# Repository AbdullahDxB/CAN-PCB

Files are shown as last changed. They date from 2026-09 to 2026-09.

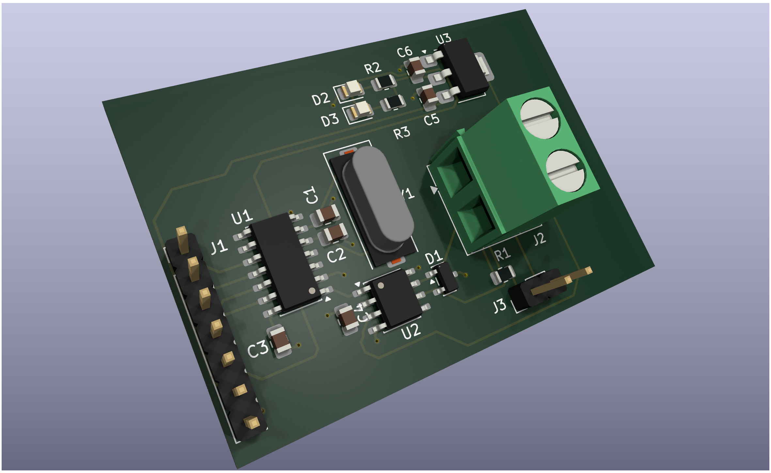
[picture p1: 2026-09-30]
docs/3DVIEW.png

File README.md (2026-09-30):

<h1 align="center">CAN Bus MCP2518 Transceiver Node</h1>

<p align="center">
  <b>High-Integrity Industrial Communication Board</b><br>

</p>

<p align="center">
  
  
  
</p>

<div align="center">
  
  **[View the 3D Board Render](./docs/3DVIEW.png)** &nbsp;&nbsp;•&nbsp;&nbsp; **[View Complete Schematic (PDF)](./docs/Schematic.pdf)**

</div>

---

## 🎯 Project Overview

A robust, two-layer CAN bus transceiver node designed for high-noise industrial environments. Built around the **MCP2518**, this board facilitates reliable, high-speed differential communication. The project demonstrates a strict adherence to layout guidelines, differential pair routing, and rigorous design rule checking (DRC).

## 🛠️ Hardware & Design Stack

* **Transceiver IC:** MCP2518
* **Protocol:** Controller Area Network (CAN)
* **EDA Tool:** KiCAD 9.0 (Schematic Capture, PCB Layout, 3D Rendering)
* **Manufacturing Prep:** Gerber Generation, BOM Management

---

## ⚙️ Design Challenges & Hardware Architecture

1. **Custom Footprint Engineering:** Discovered a critical discrepancy between the default KiCAD footprint library and the manufacturer's datasheet for the transceiver IC. To prevent solder bridging and assembly failure, I manually cross-referenced the physical dimensions and designed a custom footprint from scratch, validating pad spacing against strict DRC parameters.
2. **Differential Pair Routing:** CAN High (CANH) and CAN Low (CANL) traces were strictly routed as differential pairs, ensuring matched impedance and minimizing electromagnetic interference (EMI) in noisy industrial settings.
3. **Design Validation:** Zero errors on both the Electrical Rules Check (ERC) and Design Rules Check (DRC) prior to generating final production files.

---

## 📂 Repository Structure

* **[`hardware/`](./hardware):** Core KiCAD 9.0 project files (`.kicad_sch`, `.kicad_pcb`, `.kicad_pro`).
* **[`docs/`](./docs):** High-resolution schematic PDFs, top/bottom layer copper exports, 3D board renders, and DRC/ERC reports.
* **[`manufacturing/`](./manufacturing):** Generated Bill of Materials (BOM) and production-ready Gerber files.
* **[`datasheets/`](./datasheets):** Component reference documentation.

---
*Created by Abdullah Ajmal - August 2026*

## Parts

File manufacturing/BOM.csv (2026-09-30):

Reference | Qty | Value | DNP | Exclude from BOM | Exclude from Board | Footprint | Datasheet
C1,C2 | 2 | 22pF |  |  |  | Capacitor_SMD:C_0805_2012Metric | ~
C3,C4 | 2 | 100nF |  |  |  | Capacitor_SMD:C_0805_2012Metric | ~
C5,C6 | 2 | 10uF |  |  |  | Capacitor_SMD:C_0805_2012Metric | ~
D1 | 1 | D_TVS_Dual_AAC |  |  |  | Package_TO_SOT_SMD:SOT-23 | ~
D2,D3 | 2 | LED |  |  |  | LED_SMD:LED_0805_2012Metric | ~
J1 | 1 | Conn_01x07 |  |  |  | Connector_PinHeader_2.54mm:PinHeader_1x07_P2.54mm_Vertical | ~
J2 | 1 | Screw_Terminal_01x02 |  |  |  | TerminalBlock_Phoenix:TerminalBlock_Phoenix_MKDS-1,5-2-5.08_1x02_P5.08mm_Horizontal | ~
J3 | 1 | Conn_01x02 |  |  |  | Connector_PinHeader_2.54mm:PinHeader_1x02_P2.54mm_Vertical | ~
R1 | 1 | 120 |  |  |  | Resistor_SMD:R_0805_2012Metric | ~
R2,R3 | 2 | 1k |  |  |  | Resistor_SMD:R_0805_2012Metric | ~
U1 | 1 | MCP2518FD-xQBB |  |  |  | Package_SO:SOIC-14_3.9x8.7mm_P1.27mm | https://ww1.microchip.com/downloads/aemDocuments/documents/OTH/ProductDocuments/DataSheets/External-CAN-FD-Controller-with-SPI-Interface-DS20006027B.pdf
U2 | 1 | MCP2561-E-MF |  |  |  | Package_SO:SOIC-8_3.9x4.9mm_P1.27mm | http://ww1.microchip.com/downloads/en/DeviceDoc/25167A.pdf
U3 | 1 | AMS1117-5.0 |  |  |  | Package_TO_SOT_SMD:SOT-223-3_TabPin2 | http://www.advanced-monolithic.com/pdf/ds1117.pdf
Y1 | 1 | 20MHz |  |  |  | Crystal:Crystal_SMD_HC49-SD | ~

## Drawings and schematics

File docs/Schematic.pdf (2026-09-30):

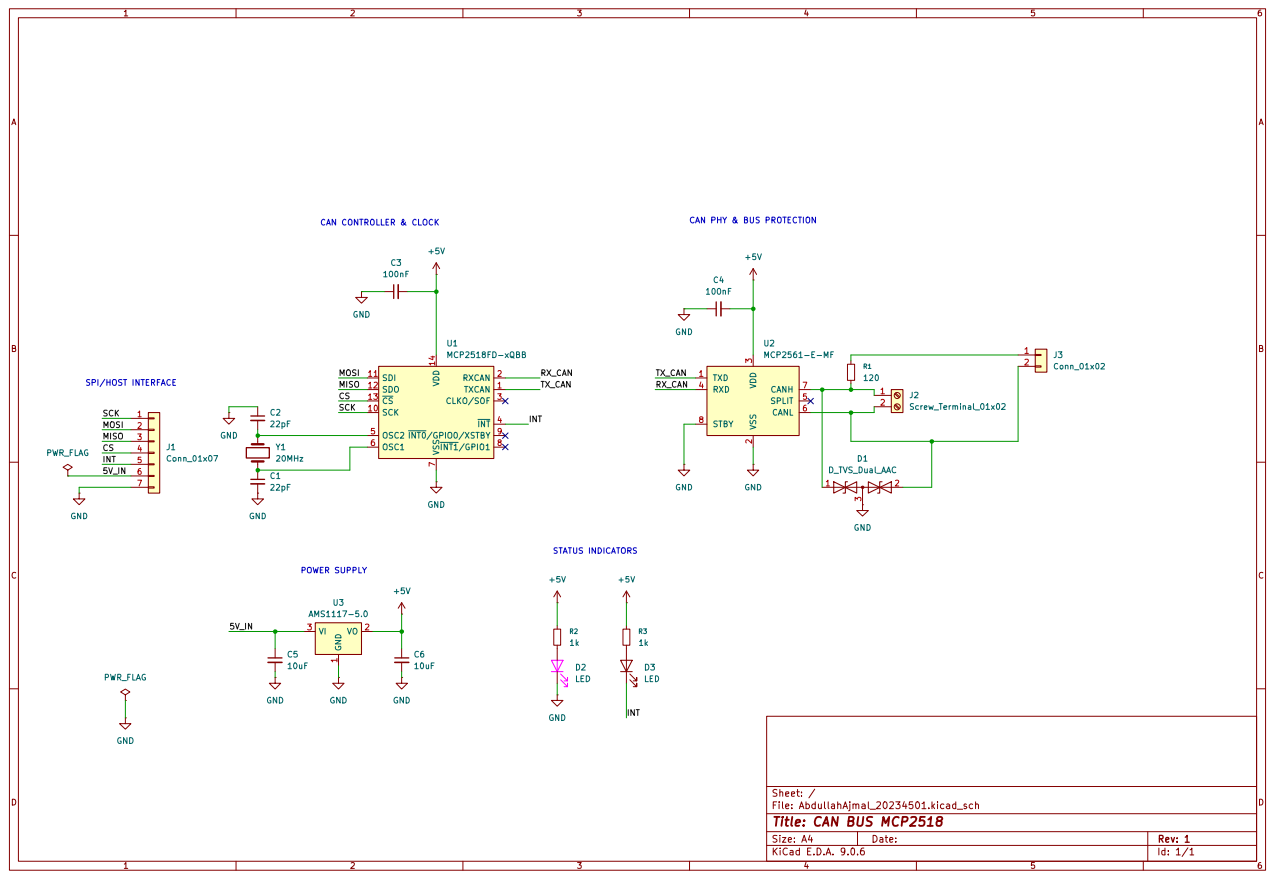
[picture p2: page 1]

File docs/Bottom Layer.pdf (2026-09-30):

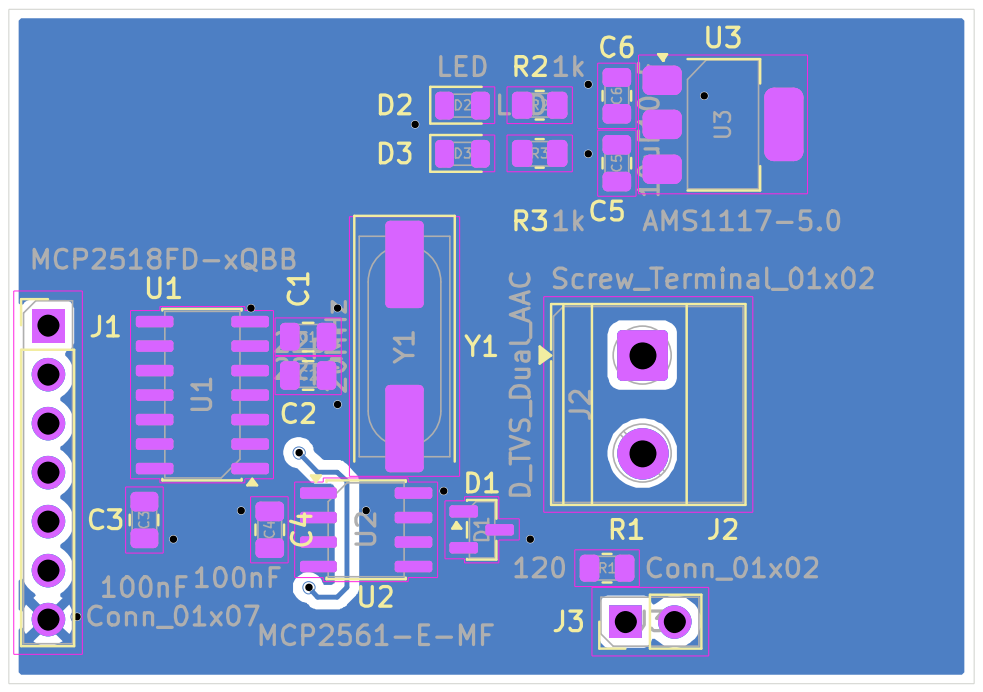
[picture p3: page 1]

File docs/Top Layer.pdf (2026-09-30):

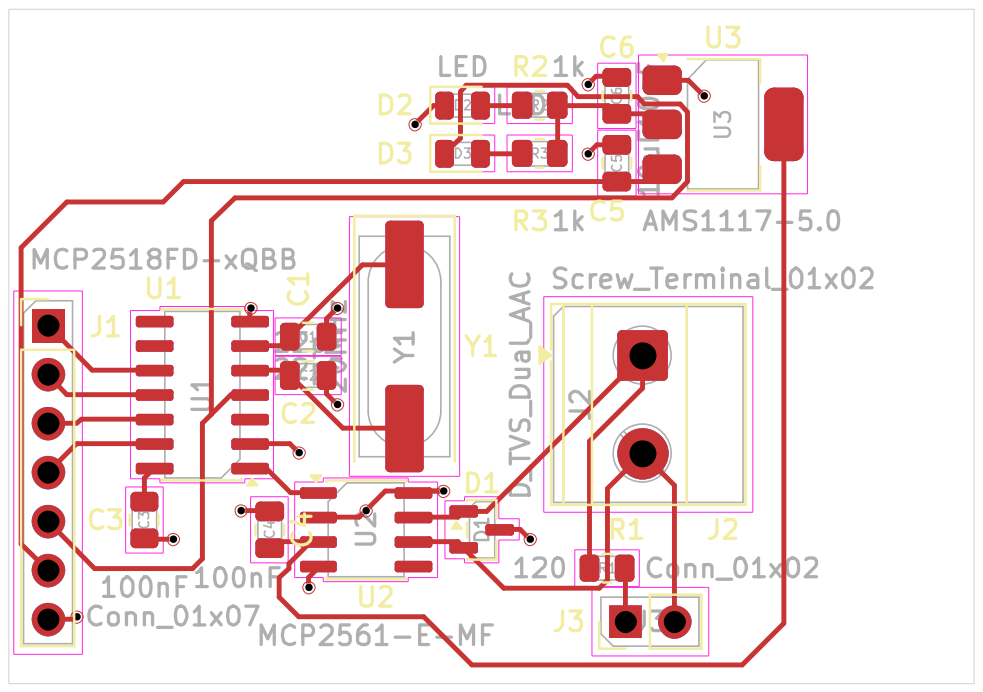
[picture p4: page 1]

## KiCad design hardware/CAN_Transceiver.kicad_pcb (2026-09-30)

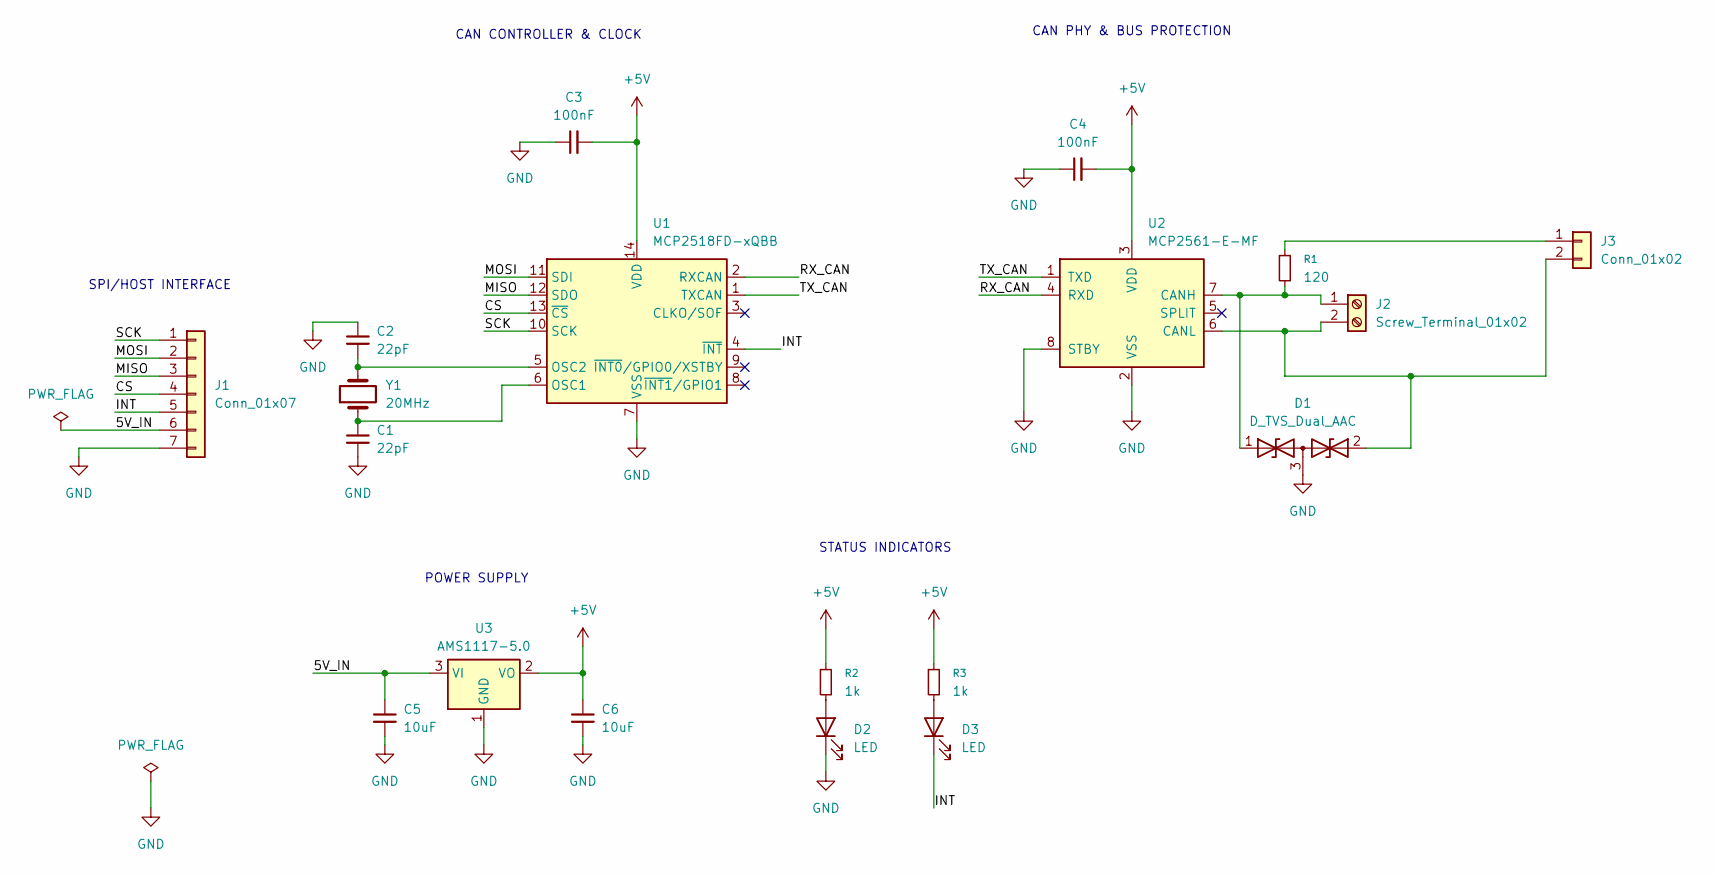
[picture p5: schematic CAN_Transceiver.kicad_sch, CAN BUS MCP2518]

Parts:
C1, C2: 22pF; C_0805_2012Metric
C3, C4: 100nF; C_0805_2012Metric
C5, C6: 10uF; C_0805_2012Metric
D1: D_TVS_Dual_AAC; SOT-23
D2, D3: LED; LED_0805_2012Metric
J1: Conn_01x07; PinHeader_1x07_P2.54mm_Vertical
J2: Screw_Terminal_01x02; TerminalBlock_Phoenix_MKDS-1,5-2-5.08_1x02_P5.08mm_Horizont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
J3: Conn_01x02; PinHeader_1x02_P2.54mm_Vertical
R1: 120; R_0805_2012Metric
R2, R3: 1k; R_0805_2012Metric
U1: MCP2518FD-xQBB; SOIC-14_3.9x8.7mm_P1.27mm
U2: MCP2561-E-MF; SOIC-8_3.9x4.9mm_P1.27mm
U3: AMS1117-5.0; SOT-223-3_TabPin2
Y1: 20MHz; Crystal_SMD_HC49-SD

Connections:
+5V: C3.2, C4.2, C6.1, R2.1, R3.1, U1.14 (VDD), U2.3 (VDD), U3.2 (VO)
/5V_IN: C5.1, J1.6, U3.3 (VI)
/CS: J1.4, U1.13 (~CS)
/INT: D3.1 (K), J1.5, U1.4 (~INT)
/MISO: J1.3, U1.12 (SDO)
/MOSI: J1.2, U1.11 (SDI)
/RX_CAN: U1.2 (RXCAN), U2.4 (RXD)
/SCK: J1.1, U1.10 (SCK)
/TX_CAN: U1.1 (TXCAN), U2.1 (TXD)
GND: C1.2, C2.1, C3.1, C4.1, C5.2, C6.2, D1.3 (common), D2.1 (K), J1.7, U1.7 (VSS), U2.2 (VSS), U2.8 (STBY), U3.1 (GND)
unnamed: D1.1 (A1), J2.1, R1.2, U2.7 (CANH)
unnamed: D1.2 (A2), J2.2, J3.2, U2.6 (CANL)
unnamed: D2.2 (A), R2.2
unnamed: D3.2 (A), R3.2
unnamed: J3.1, R1.1
unnamed: C1.1, U1.6 (OSC1), Y1.1
unnamed: C2.2, U1.5 (OSC2), Y1.2

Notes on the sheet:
CAN CONTROLLER & CLOCK
CAN PHY & BUS PROTECTION
POWER SUPPLY
STATUS INDICATORS
SPI/HOST INTERFACE

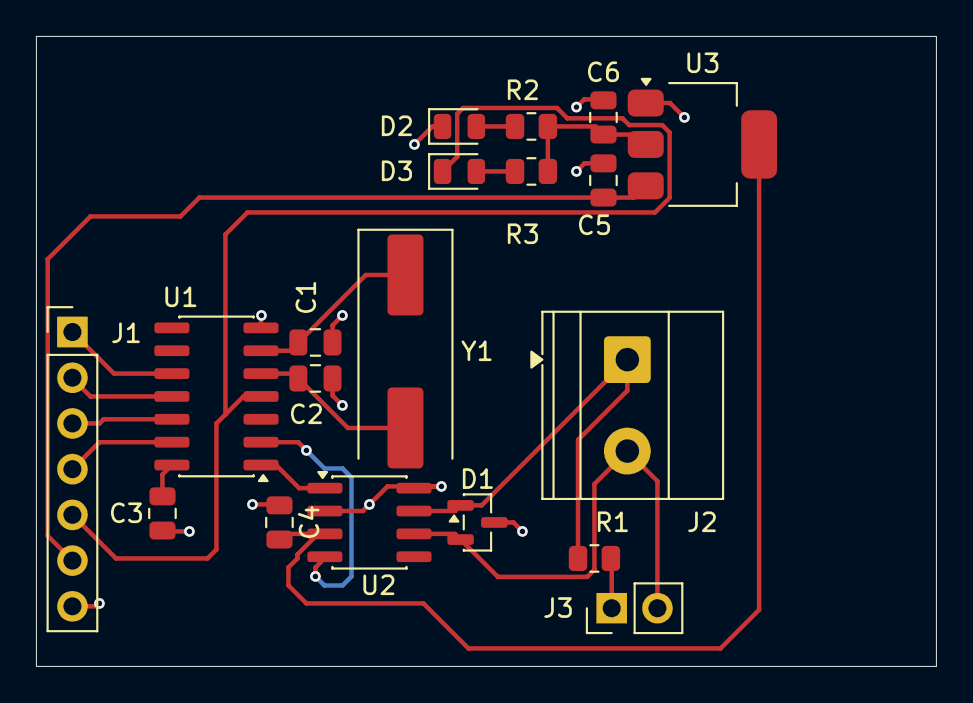
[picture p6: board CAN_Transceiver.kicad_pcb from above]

Board: 2 copper layers, 50.0 x 35.0 mm, 19 parts (0 on the bottom side), 17 nets.
